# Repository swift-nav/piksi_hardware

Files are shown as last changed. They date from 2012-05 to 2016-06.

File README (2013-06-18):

Piksi Hardware
==============

Electronics design files for Swift Navigation projects - Eagle libraries,
schematics, and board files.

Copyright
=========

All files copyright (C) 2011-2013 Swift Navigation Inc.

License
=======

All files in this repository are licensed under the Creative Commons
Attribution Share-Alike 3.0 license - text available in LICENSE.

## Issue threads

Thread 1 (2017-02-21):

Piksi Multi Carrier Board,  RS232 Port SMD component problem

RaiBearG, 2017-02-21:
I was out on the field trying to test the multi and realized that the RS232 cable wouldn't connect with one of the carrier boards. Though the Multi was working and had an RTK fix, and the TX light on the board was blinking continuously. I was able to open the console and everything. Soon realized that if I pinched the board just the right spot, the communication would happen. Turns out, one of the SMD components (most likely a resistor) popped off from the bottom. It was working fine last night, so it must have been my  handling at the field today that caused it.

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

I am using the TTL uart port for now. Seems like that component was connected to the TI multiplexer. I am assuming, without it the signal always goes to the picoblade ttl connector.
Imma build a case to help prevent this from happening. Hopefully there will be ways to make this more robust. Field testing is usually very rough and hardcore.

Rai

silverjam, 2023-07-19:
Gonna close this issue @RaiBearG ;-)

Closed 2023-07-19.

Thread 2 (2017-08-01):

Piksi Multi Wishlist Changes

soulcmdc, 2017-08-01:
- [ ] Modify /RESETIN pullup to 1k and add a 1uF capacitor in parallel to fix issue: swift-nav/piksi_v3_bug_tracking#564

soulcmdc, 2017-08-01:
Wrong repo to toss this in

Closed 2017-08-01.

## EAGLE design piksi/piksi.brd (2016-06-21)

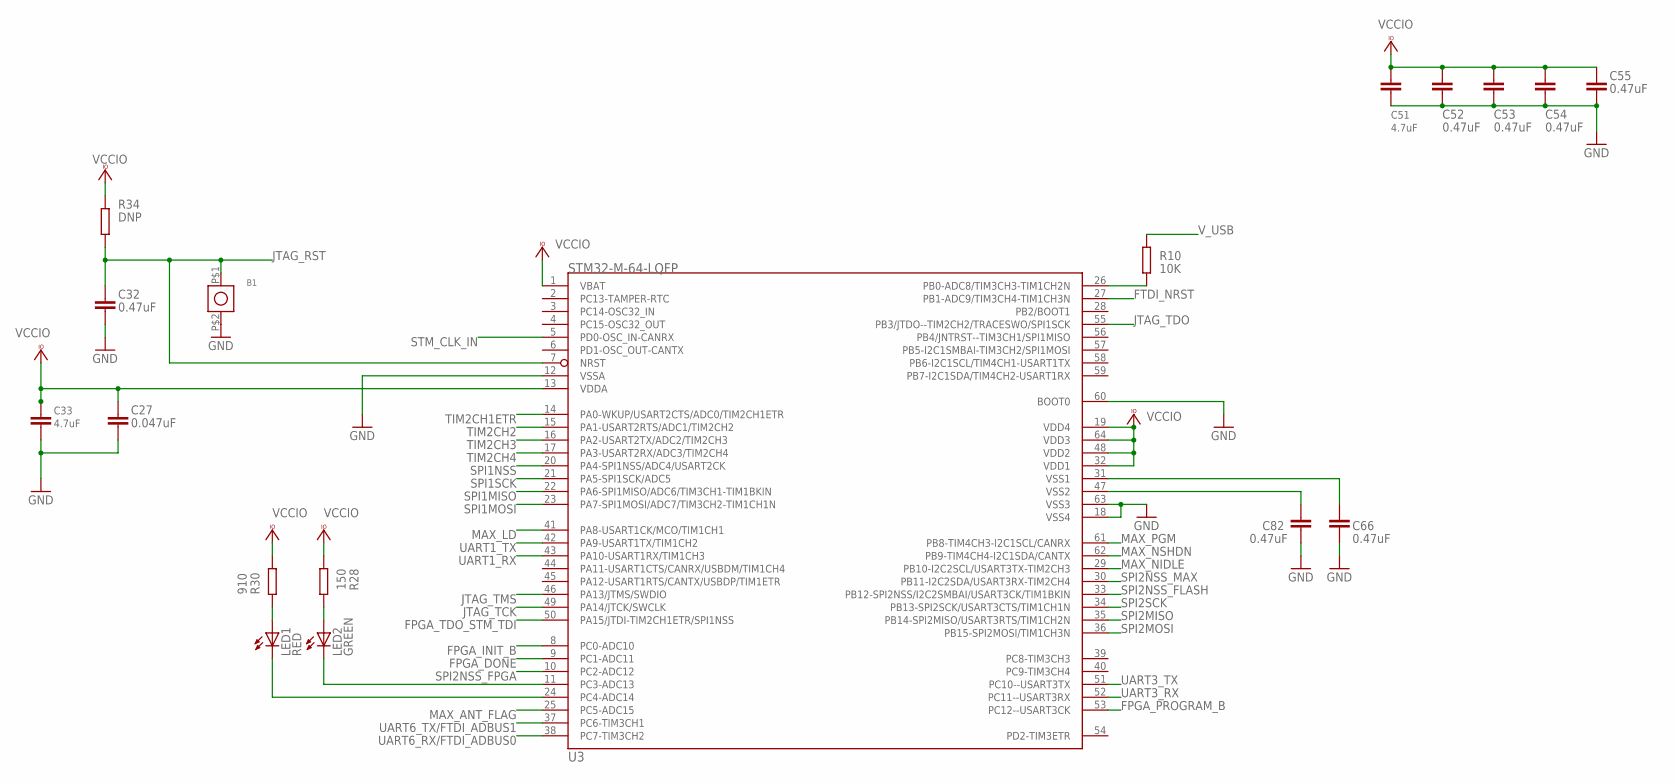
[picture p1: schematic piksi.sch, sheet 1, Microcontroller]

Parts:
B1: B3U-1000P
C27: 0.047uF; 0402-CAP
C32, C52, C53, C54, C55, C66, C82: 0.47uF; 0402-CAP
C33, C51: 4.7uF; 0603-CAP
LED1: RED; 0603-LED
LED2: GREEN; 0603-LED
R10: 10K; 0402-RES
R28: 150; 0402-RES
R30: 910; 0402-RES
R34: DNP; 0402-RES
U3: STM32-M-64-LQFP; LQFP64

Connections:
FPGA_DONE: U3.9 (PC1-ADC11); also elsewhere on the board
FPGA_INIT_B: U3.8 (PC0-ADC10); also elsewhere on the board
FPGA_PROGRAM_B: U3.53 (PC12--USART3CK); also elsewhere on the board
FPGA_TDO_STM_TDI: U3.50 (PA15/JTDI-TIM2CH1ETR/SPI1NSS); also elsewhere on the board
FTDI_NRST: U3.27 (PB1-ADC9/TIM3CH4-TIM1CH3N); also elsewhere on the board
GND: B1.P$2 (2), C27.P$2 (2), C32.P$2 (2), C33.P$1 (1), C51.P$1 (1), C52.P$2 (2), C53.P$2 (2), C54.P$2 (2), C55.P$2 (2), C66.P$2 (2), C82.P$1 (1), U3.12 (VSSA), U3.18 (VSS4), U3.60 (BOOT0), U3.63 (VSS3); also elsewhere on the board
JTAG_RST: B1.P$1 (1), C32.P$1 (1), R34.P$1 (1), U3.7 (NRST); also elsewhere on the board
JTAG_TCK: U3.49 (PA14/JTCK/SWCLK); also elsewhere on the board
JTAG_TDO: U3.55 (PB3/JTDO--TIM2CH2/TRACESWO/SPI1SCK); also elsewhere on the board
JTAG_TMS: U3.46 (PA13/JTMS/SWDIO); also elsewhere on the board
MAX_ANT_FLAG: U3.25 (PC5-ADC15); also elsewhere on the board
MAX_LD: U3.41 (PA8-USART1CK/MCO/TIM1CH1); also elsewhere on the board
MAX_NIDLE: U3.29 (PB10-I2C2SCL/USART3TX-TIM2CH3); also elsewhere on the board
MAX_NSHDN: U3.62 (PB9-TIM4CH4-I2C1SDA/CANTX); also elsewhere on the board
MAX_PGM: U3.61 (PB8-TIM4CH3-I2C1SCL/CANRX); also elsewhere on the board
unnamed: R10.P$1 (1), U3.26 (PB0-ADC8/TIM3CH3-TIM1CH2N)
unnamed: LED1.A, R30.P$1 (1)
unnamed: LED1.C, U3.24 (PC4-ADC14)
unnamed: LED2.A, R28.P$2 (2)
unnamed: LED2.C, U3.11 (PC3-ADC13)
SPI1MISO: U3.22 (PA6-SPI1MISO/ADC6/TIM3CH1-TIM1BKIN); also elsewhere on the board
SPI1MOSI: U3.23 (PA7-SPI1MOSI/ADC7/TIM3CH2-TIM1CH1N); also elsewhere on the board
SPI1NSS: U3.20 (PA4-SPI1NSS/ADC4/USART2CK); also elsewhere on the board
SPI1SCK: U3.21 (PA5-SPI1SCK/ADC5); also elsewhere on the board
SPI2MISO: U3.35 (PB14-SPI2MISO/USART3RTS/TIM1CH2N); also elsewhere on the board
SPI2MOSI: U3.36 (PB15-SPI2MOSI/TIM1CH3N); also elsewhere on the board
SPI2NSS_FLASH: U3.33 (PB12-SPI2NSS/I2C2SMBAI/USART3CK/TIM1BKIN); also elsewhere on the board
SPI2NSS_FPGA: U3.10 (PC2-ADC12)
SPI2NSS_MAX: U3.30 (PB11-I2C2SDA/USART3RX-TIM2CH4); also elsewhere on the board
SPI2SCK: U3.34 (PB13-SPI2SCK/USART3CTS/TIM1CH1N); also elsewhere on the board
STM_CLK_IN: U3.5 (PD0-OSC_IN-CANRX); also elsewhere on the board
TIM2CH1ETR: U3.14 (PA0-WKUP/USART2CTS/ADC0/TIM2CH1ETR); also elsewhere on the board
TIM2CH2: U3.15 (PA1-USART2RTS/ADC1/TIM2CH2); also elsewhere on the board
TIM2CH3: U3.16 (PA2-USART2TX/ADC2/TIM2CH3); also elsewhere on the board
TIM2CH4: U3.17 (PA3-USART2RX/ADC3/TIM2CH4); also elsewhere on the board
UART1_RX: U3.43 (PA10-USART1RX/TIM1CH3); also elsewhere on the board
UART1_TX: U3.42 (PA9-USART1TX/TIM1CH2); also elsewhere on the board
UART3_RX: U3.52 (PC11--USART3RX); also elsewhere on the board
UART3_TX: U3.51 (PC10--USART3TX); also elsewhere on the board
UART6_RX/FTDI_ADBUS0: U3.38 (PC7-TIM3CH2); also elsewhere on the board
UART6_TX/FTDI_ADBUS1: U3.37 (PC6-TIM3CH1); also elsewhere on the board
VCCIO: C27.P$1 (1), C33.P$2 (2), C51.P$2 (2), C52.P$1 (1), C53.P$1 (1), C54.P$1 (1), C55.P$1 (1), R28.P$1 (1), R30.P$2 (2), R34.P$2 (2), U3.1 (VBAT), U3.13 (VDDA), U3.19 (VDD4), U3.32 (VDD1), U3.48 (VDD2), U3.64 (VDD3); also elsewhere on the board
VSS1: C66.P$1 (1), U3.31 (VSS1)
VSS2: C82.P$2 (2), U3.47 (VSS2)
V_USB: R10.P$2 (2); also elsewhere on the board

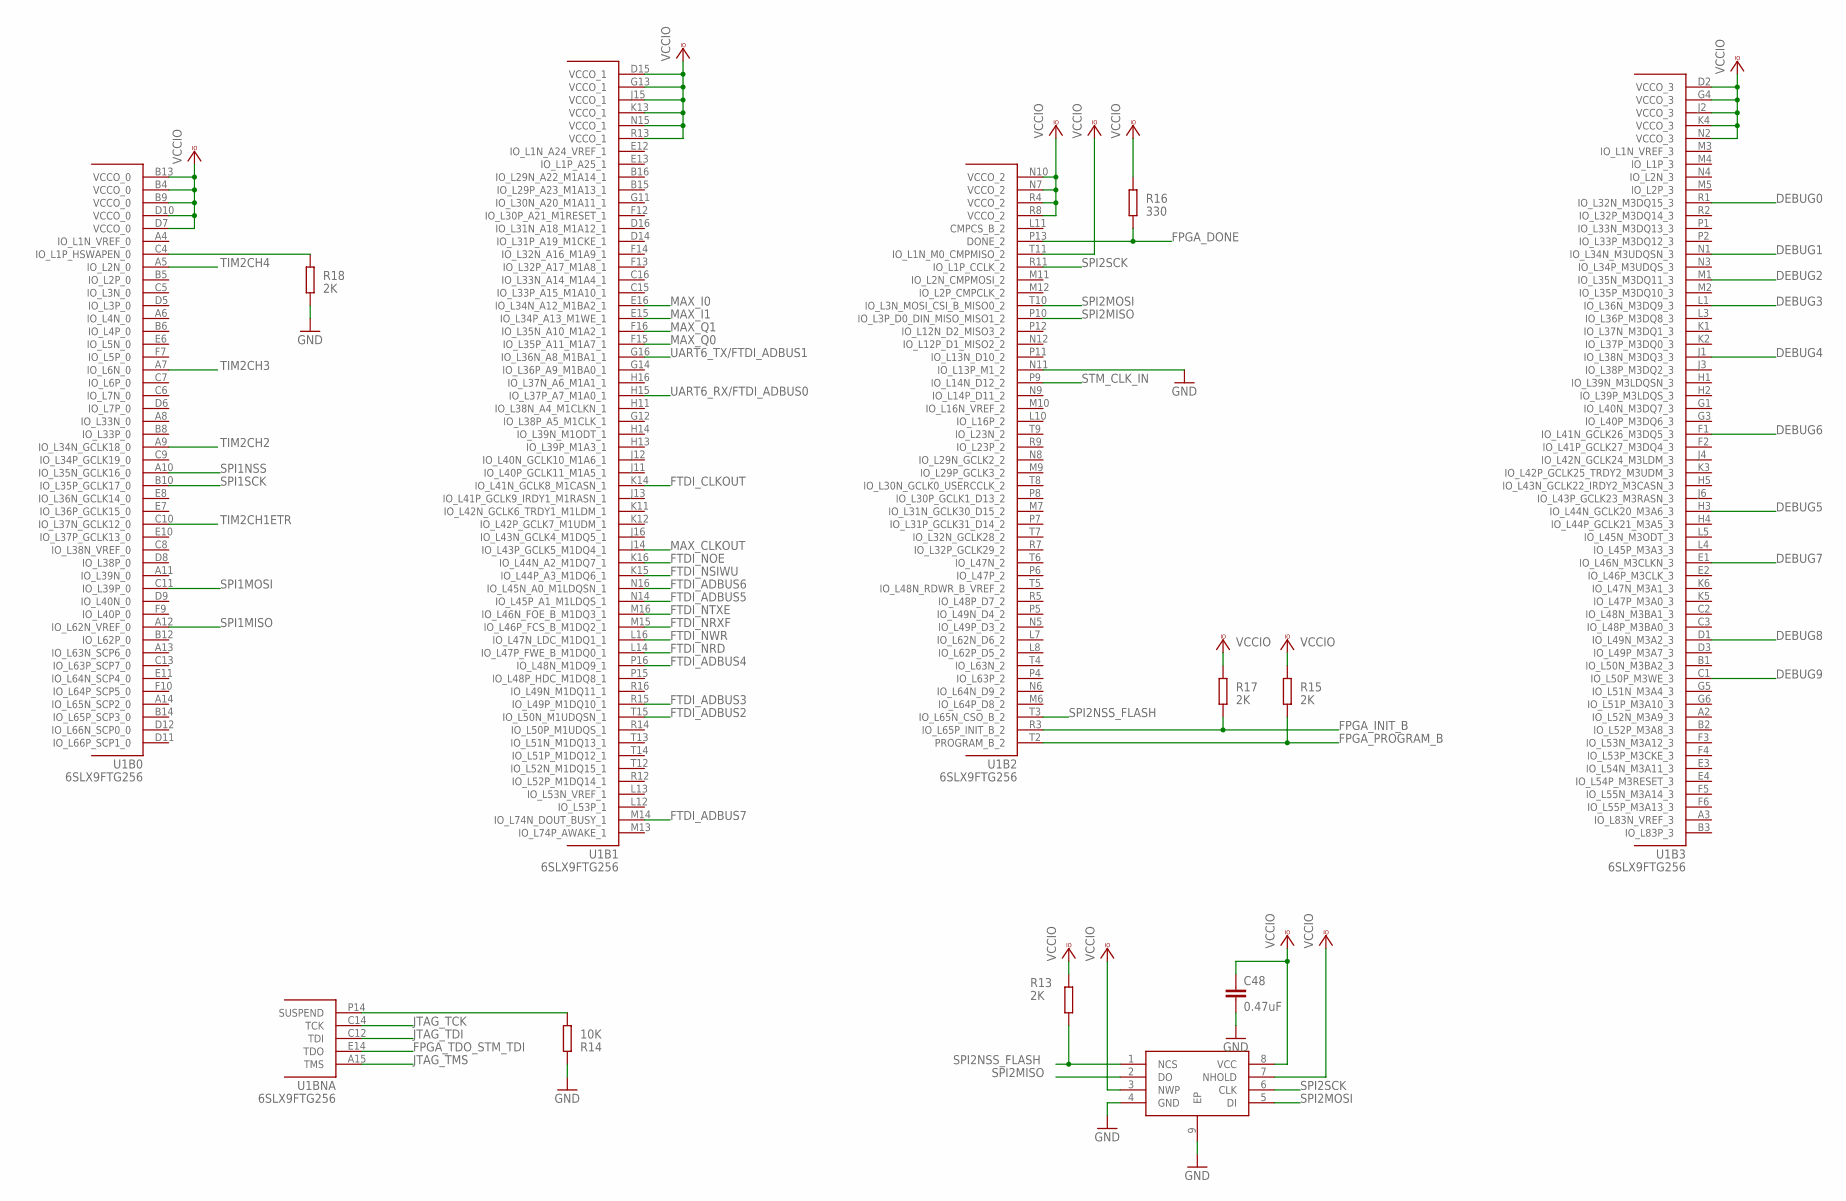
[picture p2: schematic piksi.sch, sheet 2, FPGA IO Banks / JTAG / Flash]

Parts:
C48: 0.47uF; 0402-CAP
R13, R15, R17, R18: 2K; 0402-RES
R14: 10K; 0402-RES
R16: 330; 0402-RES
U1: 6SLX9FTG256; FT256
U13: M25PX80; M25P80_MLP8

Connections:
DEBUG0: U1.R1 (IO_L32N_M3DQ15_3); also elsewhere on the board
DEBUG1: U1.N1 (IO_L34N_M3UDQSN_3); also elsewhere on the board
DEBUG2: U1.M1 (IO_L35N_M3DQ11_3); also elsewhere on the board
DEBUG3: U1.L1 (IO_L36N_M3DQ9_3); also elsewhere on the board
DEBUG4: U1.J1 (IO_L38N_M3DQ3_3); also elsewhere on the board
DEBUG5: U1.H3 (IO_L44N_GCLK20_M3A6_3); also elsewhere on the board
DEBUG6: U1.F1 (IO_L41N_GCLK26_M3DQ5_3); also elsewhere on the board
DEBUG7: U1.E1 (IO_L46N_M3CLKN_3); also elsewhere on the board
DEBUG8: U1.D1 (IO_L49N_M3A2_3); also elsewhere on the board
DEBUG9: U1.C1 (IO_L50P_M3WE_3); also elsewhere on the board
FPGA_DONE: R16.P$1 (1), U1.P13 (DONE_2); also elsewhere on the board
FPGA_INIT_B: R17.P$2 (2), U1.R3 (IO_L65P_INIT_B_2); also elsewhere on the board
FPGA_PROGRAM_B: R15.P$2 (2), U1.T2 (PROGRAM_B_2); also elsewhere on the board
FPGA_TDO_STM_TDI: U1.E14 (TDO); also elsewhere on the board
FTDI_ADBUS2: U1.T15 (IO_L50N_M1UDQSN_1); also elsewhere on the board
FTDI_ADBUS3: U1.R15 (IO_L49P_M1DQ10_1); also elsewhere on the board
FTDI_ADBUS4: U1.P16 (IO_L48N_M1DQ9_1); also elsewhere on the board
FTDI_ADBUS5: U1.N14 (IO_L45P_A1_M1LDQS_1); also elsewhere on the board
FTDI_ADBUS6: U1.N16 (IO_L45N_A0_M1LDQSN_1); also elsewhere on the board
FTDI_ADBUS7: U1.M14 (IO_L74N_DOUT_BUSY_1); also elsewhere on the board
FTDI_CLKOUT: U1.K14 (IO_L41N_GCLK8_M1CASN_1); also elsewhere on the board
FTDI_NOE: U1.K16 (IO_L44N_A2_M1DQ7_1); also elsewhere on the board
FTDI_NRD: U1.L14 (IO_L47P_FWE_B_M1DQ0_1); also elsewhere on the board
FTDI_NRXF: U1.M15 (IO_L46P_FCS_B_M1DQ2_1); also elsewhere on the board
FTDI_NSIWU: U1.K15 (IO_L44P_A3_M1DQ6_1); also elsewhere on the board
FTDI_NTXE: U1.M16 (IO_L46N_FOE_B_M1DQ3_1); also elsewhere on the board
FTDI_NWR: U1.L16 (IO_L47N_LDC_M1DQ1_1); also elsewhere on the board
GND: C48.P$2 (2), R14.P$2 (2), R18.P$1 (1), U1.N11 (IO_L13P_M1_2), U13.4 (GND), U13.9 (EP); also elsewhere on the board
JTAG_TCK: U1.C14 (TCK); also elsewhere on the board
JTAG_TDI: U1.C12 (TDI); also elsewhere on the board
JTAG_TMS: U1.A15 (TMS); also elsewhere on the board
MAX_CLKOUT: U1.J14 (IO_L43P_GCLK5_M1DQ4_1); also elsewhere on the board
MAX_I0: U1.E16 (IO_L34N_A12_M1BA2_1); also elsewhere on the board
MAX_I1: U1.E15 (IO_L34P_A13_M1WE_1); also elsewhere on the board
MAX_Q0: U1.F15 (IO_L35P_A11_M1A7_1); also elsewhere on the board
MAX_Q1: U1.F16 (IO_L35N_A10_M1A2_1); also elsewhere on the board
unnamed: R18.P$2 (2), U1.C4 (IO_L1P_HSWAPEN_0)
unnamed: R14.P$1 (1), U1.P14 (SUSPEND)
SPI1MISO: U1.A12 (IO_L62N_VREF_0); also elsewhere on the board
SPI1MOSI: U1.C11 (IO_L39P_0); also elsewhere on the board
SPI1NSS: U1.A10 (IO_L35N_GCLK16_0); also elsewhere on the board
SPI1SCK: U1.B10 (IO_L35P_GCLK17_0); also elsewhere on the board
SPI2MISO: U1.P10 (IO_L3P_D0_DIN_MISO_MISO1_2), U13.2 (DO); also elsewhere on the board
SPI2MOSI: U1.T10 (IO_L3N_MOSI_CSI_B_MISO0_2), U13.5 (DI); also elsewhere on the board
SPI2NSS_FLASH: R13.P$1 (1), U1.T3 (IO_L65N_CSO_B_2), U13.1 (NCS); also elsewhere on the board
SPI2SCK: U1.R11 (IO_L1P_CCLK_2), U13.6 (CLK); also elsewhere on the board
STM_CLK_IN: U1.P9 (IO_L14N_D12_2); also elsewhere on the board
TIM2CH1ETR: U1.C10 (IO_L37N_GCLK12_0); also elsewhere on the board
TIM2CH2: U1.A9 (IO_L34N_GCLK18_0); also elsewhere on the board
TIM2CH3: U1.A7 (IO_L6N_0); also elsewhere on the board
TIM2CH4: U1.A5 (IO_L2N_0); also elsewhere on the board
UART6_RX/FTDI_ADBUS0: U1.H15 (IO_L37P_A7_M1A0_1); also elsewhere on the board
UART6_TX/FTDI_ADBUS1: U1.G16 (IO_L36N_A8_M1BA1_1); also elsewhere on the board
VCCIO: C48.P$1 (1), R13.P$2 (2), R15.P$1 (1), R16.P$2 (2), R17.P$1 (1), U1.B4 (VCCO_0), U1.B9 (VCCO_0), U1.B13 (VCCO_0), U1.D2 (VCCO_3), U1.D7 (VCCO_0), U1.D10 (VCCO_0), U1.D15 (VCCO_1), U1.G4 (VCCO_3), U1.G13 (VCCO_1), U1.J2 (VCCO_3), U1.J15 (VCCO_1), U1.K4 (VCCO_3), U1.K13 (VCCO_1), U1.N2 (VCCO_3), U1.N7 (VCCO_2), U1.N10 (VCCO_2), U1.N15 (VCCO_1), U1.R4 (VCCO_2), U1.R8 (VCCO_2), U1.R13 (VCCO_1), U1.T11 (IO_L1N_M0_CMPMISO_2), U13.3 (NWP), U13.7 (NHOLD), U13.8 (VCC); also elsewhere on the board

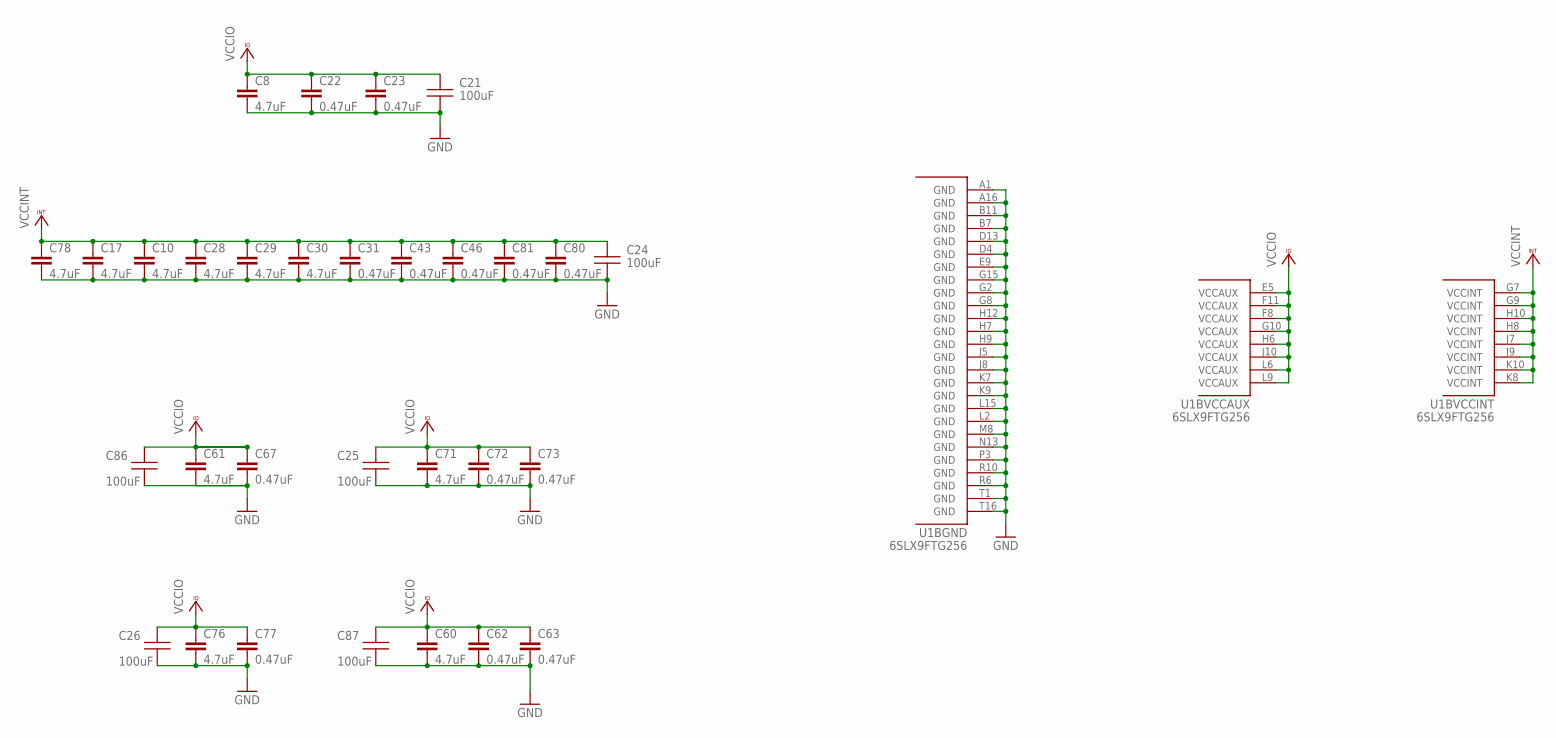
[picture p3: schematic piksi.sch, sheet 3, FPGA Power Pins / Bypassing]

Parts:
C8, C10, C17, C28, C29, C30, C60, C61, C71, C76, C78: 4.7uF; 0603-CAP
C21, C24, C25, C26, C86, C87: 100uF; C1210
C22, C23, C31, C43, C46, C62, C63, C67, C72, C73, C77, C80, C81: 0.47uF; 0402-CAP
U1: 6SLX9FTG256; FT256

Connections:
GND: C8.P$2 (2), C10.P$2 (2), C17.P$2 (2), C21.P$2 (2), C22.P$2 (2), C23.P$2 (2), C24.P$2 (2), C25.P$2 (2), C26.P$2 (2), C28.P$2 (2), C29.P$2 (2), C30.P$2 (2), C31.P$2 (2), C43.P$2 (2), C46.P$2 (2), C60.P$2 (2), C61.P$2 (2), C62.P$2 (2), C63.P$2 (2), C67.P$2 (2), C71.P$2 (2), C72.P$2 (2), C73.P$2 (2), C76.P$2 (2), C77.P$2 (2), C78.P$2 (2), C80.P$2 (2), C81.P$2 (2), C86.P$2 (2), C87.P$2 (2), U1.A1 (GND), U1.A16 (GND), U1.B7 (GND), U1.B11 (GND), U1.D4 (GND), U1.D13 (GND), U1.E9 (GND), U1.G2 (GND), U1.G8 (GND), U1.G15 (GND), U1.H7 (GND), U1.H9 (GND), U1.H12 (GND), U1.J5 (GND), U1.J8 (GND), U1.K7 (GND), U1.K9 (GND), U1.L2 (GND), U1.L15 (GND), U1.M8 (GND), U1.N13 (GND), U1.P3 (GND), U1.R6 (GND), U1.R10 (GND), U1.T1 (GND), U1.T16 (GND); also elsewhere on the board
VCCINT: C10.P$1 (1), C17.P$1 (1), C24.P$1 (1), C28.P$1 (1), C29.P$1 (1), C30.P$1 (1), C31.P$1 (1), C43.P$1 (1), C46.P$1 (1), C78.P$1 (1), C80.P$1 (1), C81.P$1 (1), U1.G7 (VCCINT), U1.G9 (VCCINT), U1.H8 (VCCINT), U1.H10 (VCCINT), U1.J7 (VCCINT), U1.J9 (VCCINT), U1.K8 (VCCINT), U1.K10 (VCCINT); also elsewhere on the board
VCCIO: C8.P$1 (1), C21.P$1 (1), C22.P$1 (1), C23.P$1 (1), C25.P$1 (1), C26.P$1 (1), C60.P$1 (1), C61.P$1 (1), C62.P$1 (1), C63.P$1 (1), C67.P$1 (1), C71.P$1 (1), C72.P$1 (1), C73.P$1 (1), C76.P$1 (1), C77.P$1 (1), C86.P$1 (1), C87.P$1 (1), U1.E5 (VCCAUX), U1.F8 (VCCAUX), U1.F11 (VCCAUX), U1.G10 (VCCAUX), U1.H6 (VCCAUX), U1.J10 (VCCAUX), U1.L6 (VCCAUX), U1.L9 (VCCAUX); also elsewhere on the board

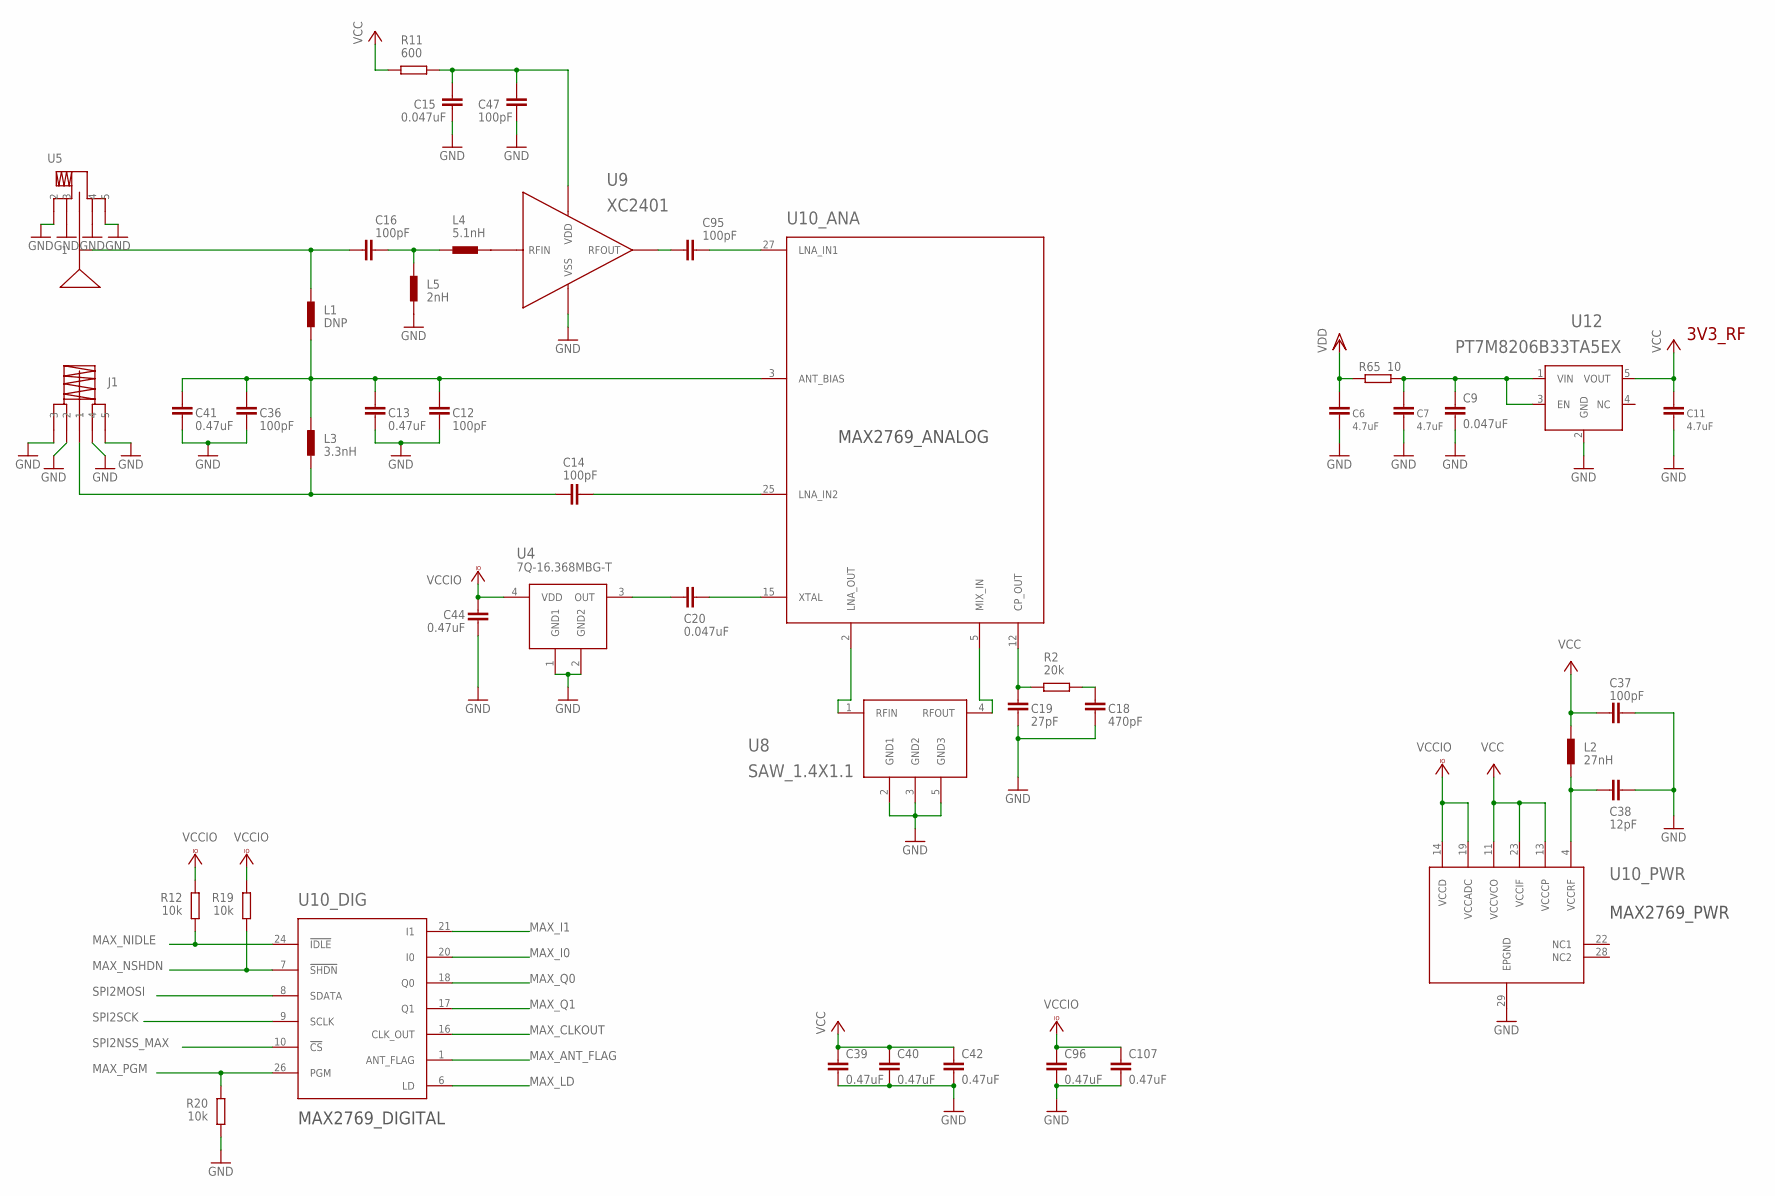
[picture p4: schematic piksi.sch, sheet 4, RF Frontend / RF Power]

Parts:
C6, C7, C11: 4.7uF; 0603-CAP
C9, C15, C20: 0.047uF; 0402-CAP
C12, C14, C16, C36, C37, C47, C95: 100pF; 0402-CAP
C13, C39, C40, C41, C42, C44, C96, C107: 0.47uF; 0402-CAP
C18: 470pF; 0402-CAP
C19: 27pF; 0402-CAP
C38: 12pF; 0402-CAP
J1: SMA_EDGE
L1: DNP; 0402-IND
L2: 27nH; 0402-IND
L3: 3.3nH; 0402-IND
L4: 5.1nH; 0402-IND
L5: 2nH; 0402-IND
R2: 20k; 0402-RES
R11: 600; 0402-RES
R12, R19, R20: 10k; 0402-RES
R65: 10; 0402-RES
U4: 7Q-16.368MBG-T; TCX_7Q
U5: SMA_PATCH_SMDGND
U8: SAW_1.4X1.1
U9: XC2401
U10: MAX2769
U12: PT7M8206B33TA5EX

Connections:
FE_CLK: C20.P$2 (2), U4.3 (OUT)
GND: C6.P$1 (1), C7.P$1 (1), C9.P$2 (2), C11.P$1 (1), C12.P$1 (1), C13.P$1 (1), C15.P$1 (1), C18.P$2 (2), C19.P$2 (2), C36.P$1 (1), C37.P$2 (2), C38.P$2 (2), C39.P$2 (2), C40.P$2 (2), C41.P$1 (1), C42.P$2 (2), C44.P$2 (2), C47.P$1 (1), C96.P$2 (2), C107.P$2 (2), J1.P2 (2), J1.P3 (3), J1.P4 (4), J1.P5 (5), L5.P$1 (1), R20.P$1 (1), U4.1 (GND1), U4.2 (GND2), U5.2, U5.3, U5.4, U5.5, U8.2 (GND1), U8.3 (GND2), U8.5 (GND3), U9.3 (VSS), U10.29 (EPGND), U12.2 (GND); also elsewhere on the board
MAX_ANT_FLAG: U10.1 (ANT_FLAG); also elsewhere on the board
MAX_CLKOUT: U10.16 (CLK_OUT); also elsewhere on the board
MAX_I0: U10.20 (I0); also elsewhere on the board
MAX_I1: U10.21 (I1); also elsewhere on the board
MAX_LD: U10.6 (LD); also elsewhere on the board
MAX_NIDLE: R12.P$1 (1), U10.24 (!IDLE); also elsewhere on the board
MAX_NSHDN: R19.P$1 (1), U10.7 (!SHDN); also elsewhere on the board
MAX_PGM: R20.P$2 (2), U10.26 (PGM); also elsewhere on the board
MAX_Q0: U10.18 (Q0); also elsewhere on the board
MAX_Q1: U10.17 (Q1); also elsewhere on the board
unnamed: L4.P$2 (2), U9.4 (RFIN)
unnamed: C18.P$1 (1), R2.P$1 (1)
unnamed: C19.P$1 (1), R2.P$2 (2), U10.12 (CP_OUT)
unnamed: U8.1 (RFIN), U10.2 (LNA_OUT)
unnamed: C20.P$1 (1), U10.15 (XTAL)
unnamed: U8.4 (RFOUT), U10.5 (MIX_IN)
unnamed: C14.P$1 (1), J1.P1 (1), L3.P$1 (1)
unnamed: C12.P$2 (2), C13.P$2 (2), C36.P$2 (2), C41.P$2 (2), L1.P$1 (1), L3.P$2 (2), U10.3 (ANT_BIAS)
unnamed: C95.P$2 (2), U10.27 (LNA_IN1)
unnamed: C16.P$1 (1), L1.P$2 (2), U5.1
unnamed: C38.P$1 (1), L2.P$1 (1), U10.4 (VCCRF)
unnamed: C14.P$2 (2), U10.25 (LNA_IN2)
unnamed: C16.P$2 (2), L4.P$1 (1), L5.P$2 (2)
unnamed: C95.P$1 (1), U9.2 (RFOUT)
unnamed: C15.P$2 (2), C47.P$2 (2), R11.P$1 (1), U9.1 (VDD)
unnamed: C7.P$2 (2), C9.P$1 (1), R65.P$2 (2), U12.1 (VIN), U12.3 (EN)
SPI2MOSI: U10.8 (SDATA); also elsewhere on the board
SPI2NSS_MAX: U10.10 (!CS); also elsewhere on the board
SPI2SCK: U10.9 (SCLK); also elsewhere on the board
VCC: C11.P$2 (2), C37.P$1 (1), C39.P$1 (1), C40.P$1 (1), C42.P$1 (1), L2.P$2 (2), R11.P$2 (2), U10.11 (VCCVCO), U10.13 (VCCCP), U10.23 (VCCIF), U12.5 (VOUT)
VCCIO: C44.P$1 (1), C96.P$1 (1), C107.P$1 (1), R12.P$2 (2), R19.P$2 (2), U4.4 (VDD), U10.14 (VCCD), U10.19 (VCCADC); also elsewhere on the board
VDD: C6.P$2 (2), R65.P$1 (1); also elsewhere on the board

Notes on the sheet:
3V3_RF

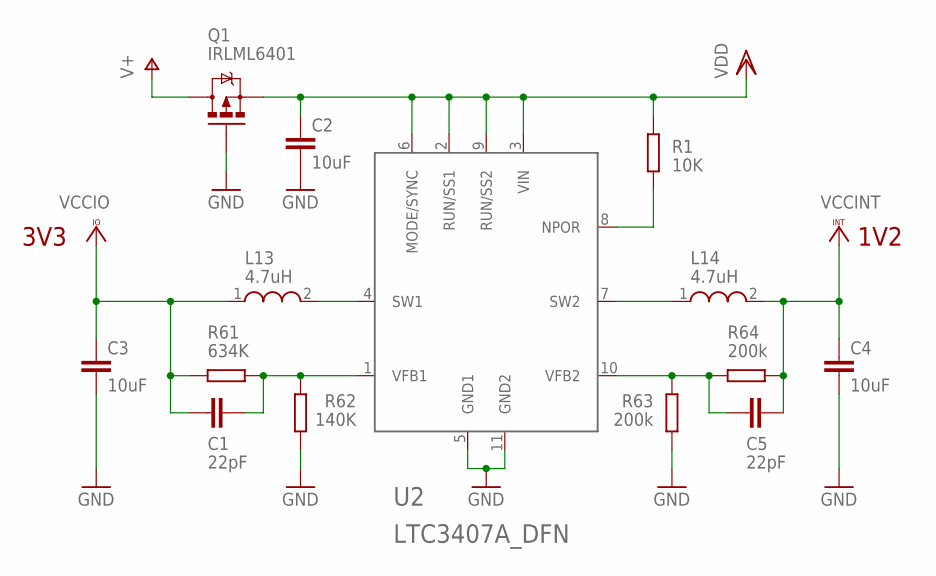
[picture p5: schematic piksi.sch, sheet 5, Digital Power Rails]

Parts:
C1, C5: 22pF; 0402-CAP
C2, C3, C4: 10uF; 1206-CAP
L13, L14: 4.7uH; LQM2HPN4R7MG0L
Q1: IRLML6401; SOT23-3
R1: 10K; 0402-RES
R61: 634K; 0402-RES
R62: 140K; 0402-RES
R63, R64: 200k; 0402-RES
U2: LTC3407A_DFN; DFN10

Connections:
GND: C2.P$2 (2), C3.P$2 (2), C4.P$2 (2), Q1.1 (G), R62.P$2 (2), R63.P$2 (2), U2.5 (GND1), U2.11 (GND2); also elsewhere on the board
unnamed: R1.P$1 (1), U2.8 (NPOR)
unnamed: L13.2, U2.4 (SW1)
unnamed: L14.1, U2.7 (SW2)
unnamed: C1.P$1 (1), R61.P$1 (1), R62.P$1 (1), U2.1 (VFB1)
unnamed: C5.P$2 (2), R63.P$1 (1), R64.P$1 (1), U2.10 (VFB2)
V+: Q1.3 (D); also elsewhere on the board
VCCINT: C4.P$1 (1), C5.P$1 (1), L14.2, R64.P$2 (2); also elsewhere on the board
VCCIO: C1.P$2 (2), C3.P$1 (1), L13.1, R61.P$2 (2); also elsewhere on the board
VDD: C2.P$1 (1), Q1.2 (S), R1.P$2 (2), U2.2 (RUN/SS1), U2.3 (VIN), U2.6 (MODE/SYNC), U2.9 (RUN/SS2); also elsewhere on the board

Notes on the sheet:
1V2
3V3

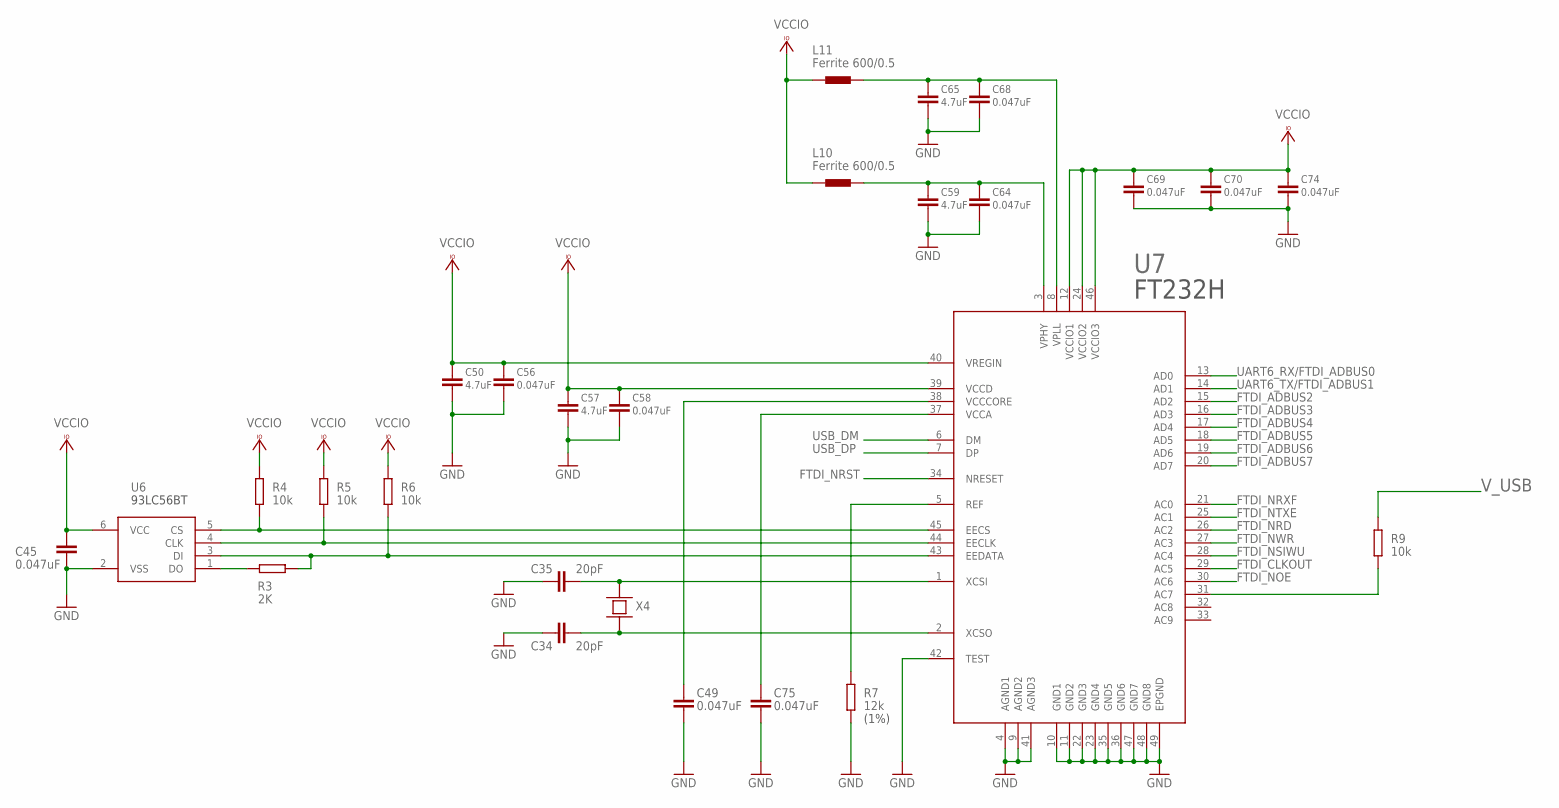
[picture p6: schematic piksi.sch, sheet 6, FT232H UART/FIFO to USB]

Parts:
C34, C35: 20pF; 0402-CAP
C45: 0.047uF; C0402
C49, C56, C58, C64, C68, C70, C74, C75: 0.047uF; 0402-CAP
C50, C57, C59, C65: 4.7uF; 0603-CAP
C69: 0.047uF; C0603K
L10, L11: Ferrite 600/0.5; 0805-IND
R3: 2K; 0402-RES
R4, R5, R6, R9: 10k; 0402-RES
R7: 12k; 0402-RES
U6: 93LC56BT-I/OT; 93AA56BT-I/OT
U7: FT232HQ
X4: NX5032GA-12M; NX5032GA

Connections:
FTDI_ADBUS2: U7.15 (AD2); also elsewhere on the board
FTDI_ADBUS3: U7.16 (AD3); also elsewhere on the board
FTDI_ADBUS4: U7.17 (AD4); also elsewhere on the board
FTDI_ADBUS5: U7.18 (AD5); also elsewhere on the board
FTDI_ADBUS6: U7.19 (AD6); also elsewhere on the board
FTDI_ADBUS7: U7.20 (AD7); also elsewhere on the board
FTDI_CLKOUT: U7.29 (AC5); also elsewhere on the board
FTDI_NOE: U7.30 (AC6); also elsewhere on the board
FTDI_NRD: U7.26 (AC2); also elsewhere on the board
FTDI_NRST: U7.34 (NRESET); also elsewhere on the board
FTDI_NRXF: U7.21 (AC0); also elsewhere on the board
FTDI_NSIWU: U7.28 (AC4); also elsewhere on the board
FTDI_NTXE: U7.25 (AC1); also elsewhere on the board
FTDI_NWR: U7.27 (AC3); also elsewhere on the board
GND: C34.P$2 (2), C35.P$2 (2), C45.2, C49.P$2 (2), C50.P$1 (1), C56.P$2 (2), C57.P$1 (1), C58.P$2 (2), C59.P$1 (1), C64.P$2 (2), C65.P$1 (1), C68.P$2 (2), C69.2, C70.P$2 (2), C74.P$2 (2), C75.P$2 (2), R7.P$2 (2), U6.2 (VSS), U7.4 (AGND1), U7.9 (AGND2), U7.10 (GND1), U7.11 (GND2), U7.22 (GND3), U7.23 (GND4), U7.35 (GND5), U7.36 (GND6), U7.41 (AGND3), U7.42 (TEST), U7.47 (GND7), U7.48 (GND8), U7.49 (EPGND); also elsewhere on the board
unnamed: C34.P$1 (1), U7.2 (XCSO), X4.2
unnamed: C35.P$1 (1), U7.1 (XCSI), X4.1
unnamed: C49.P$1 (1), U7.38 (VCCCORE)
unnamed: R9.P$2 (2), U7.31 (AC7)
unnamed: C65.P$2 (2), C68.P$1 (1), L11.P$2 (2), U7.8 (VPLL)
unnamed: R4.P$2 (2), U6.5 (CS), U7.45 (EECS)
unnamed: R5.P$2 (2), U6.4 (CLK), U7.44 (EECLK)
unnamed: R3.P$1 (1), R6.P$2 (2), U6.3 (DI), U7.43 (EEDATA)
unnamed: R3.P$2 (2), U6.1 (DO)
unnamed: C59.P$2 (2), C64.P$1 (1), L10.P$2 (2), U7.3 (VPHY)
unnamed: C75.P$1 (1), U7.37 (VCCA)
unnamed: R7.P$1 (1), U7.5 (REF)
UART6_RX/FTDI_ADBUS0: U7.13 (AD0); also elsewhere on the board
UART6_TX/FTDI_ADBUS1: U7.14 (AD1); also elsewhere on the board
USB_DM: U7.6 (DM); also elsewhere on the board
USB_DP: U7.7 (DP); also elsewhere on the board
VCCIO: C45.1, C50.P$2 (2), C56.P$1 (1), C57.P$2 (2), C58.P$1 (1), C69.1, C70.P$1 (1), C74.P$1 (1), L10.P$1 (1), L11.P$1 (1), R4.P$1 (1), R5.P$1 (1), R6.P$1 (1), U6.6 (VCC), U7.12 (VCCIO1), U7.24 (VCCIO2), U7.39 (VCCD), U7.40 (VREGIN), U7.46 (VCCIO3); also elsewhere on the board
V_USB: R9.P$1 (1); also elsewhere on the board

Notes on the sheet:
(1%)

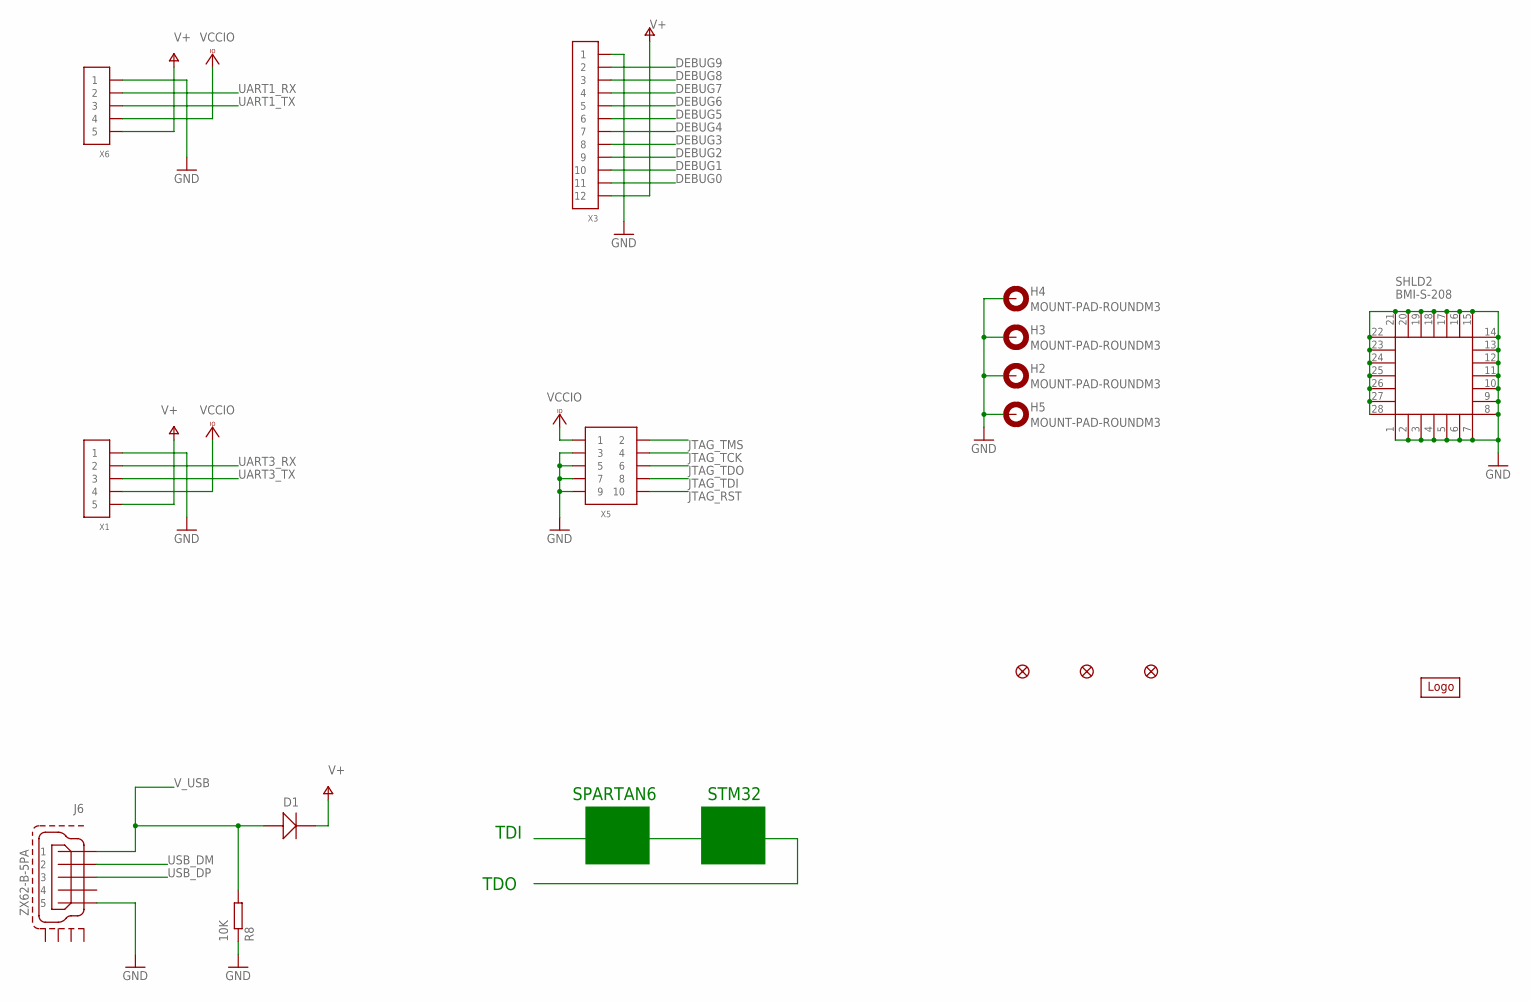
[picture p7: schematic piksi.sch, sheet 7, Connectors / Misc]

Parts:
D1: MBR0520; SOD-123
H2, H3, H4, H5: MOUNT-PAD-ROUNDM3; M3-PAD
J6: ZX62-B-5PA
JP8, JP9, JP10: FIDUCIAL1.5X3; FIDUCIAL-1.5X3
R8: 10K; 0402-RES
SHLD2: BMI-S-208
U$2: LOGOLOGO3_SMALL; LOGO3_SMALL
X1, X6: CONN_5-1-53261; PB-53261-05
X3: FPGA DEBUG; PB-53261-12
X5: CONN_5-2; FTSH-105-D

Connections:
DEBUG0: X3.11; also elsewhere on the board
DEBUG1: X3.10; also elsewhere on the board
DEBUG2: X3.9; also elsewhere on the board
DEBUG3: X3.8; also elsewhere on the board
DEBUG4: X3.7; also elsewhere on the board
DEBUG5: X3.6; also elsewhere on the board
DEBUG6: X3.5; also elsewhere on the board
DEBUG7: X3.4; also elsewhere on the board
DEBUG8: X3.3; also elsewhere on the board
DEBUG9: X3.2; also elsewhere on the board
GND: H2.B3,0, H3.B3,0, H4.B3,0, H5.B3,0, J6.PIN_5 (5), R8.P$1 (1), SHLD2.1, SHLD2.2, SHLD2.3, SHLD2.4, SHLD2.5, SHLD2.6, SHLD2.7, SHLD2.8, SHLD2.9, SHLD2.10, SHLD2.11, SHLD2.12, SHLD2.13, SHLD2.14, SHLD2.15, SHLD2.16, SHLD2.17, SHLD2.18, SHLD2.19, SHLD2.20, SHLD2.21, SHLD2.22, SHLD2.23, SHLD2.24, SHLD2.25, SHLD2.26, SHLD2.27, SHLD2.28, X1.1, X3.1, X5.3, X5.5, X5.7, X5.9, X6.1; also elsewhere on the board
JTAG_RST: X5.10; also elsewhere on the board
JTAG_TCK: X5.4; also elsewhere on the board
JTAG_TDI: X5.8; also elsewhere on the board
JTAG_TDO: X5.6; also elsewhere on the board
JTAG_TMS: X5.2; also elsewhere on the board
UART1_RX: X6.2; also elsewhere on the board
UART1_TX: X6.3; also elsewhere on the board
UART3_RX: X1.2; also elsewhere on the board
UART3_TX: X1.3; also elsewhere on the board
USB_DM: J6.PIN_2 (2); also elsewhere on the board
USB_DP: J6.PIN_3 (3); also elsewhere on the board
V+: D1.2, X1.5, X3.12, X6.5; also elsewhere on the board
VCCIO: X1.4, X5.1, X6.4; also elsewhere on the board
V_USB: D1.1, J6.PIN_1 (1), R8.P$2 (2); also elsewhere on the board

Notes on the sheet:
TDI
TDO
STM32
SPARTAN6

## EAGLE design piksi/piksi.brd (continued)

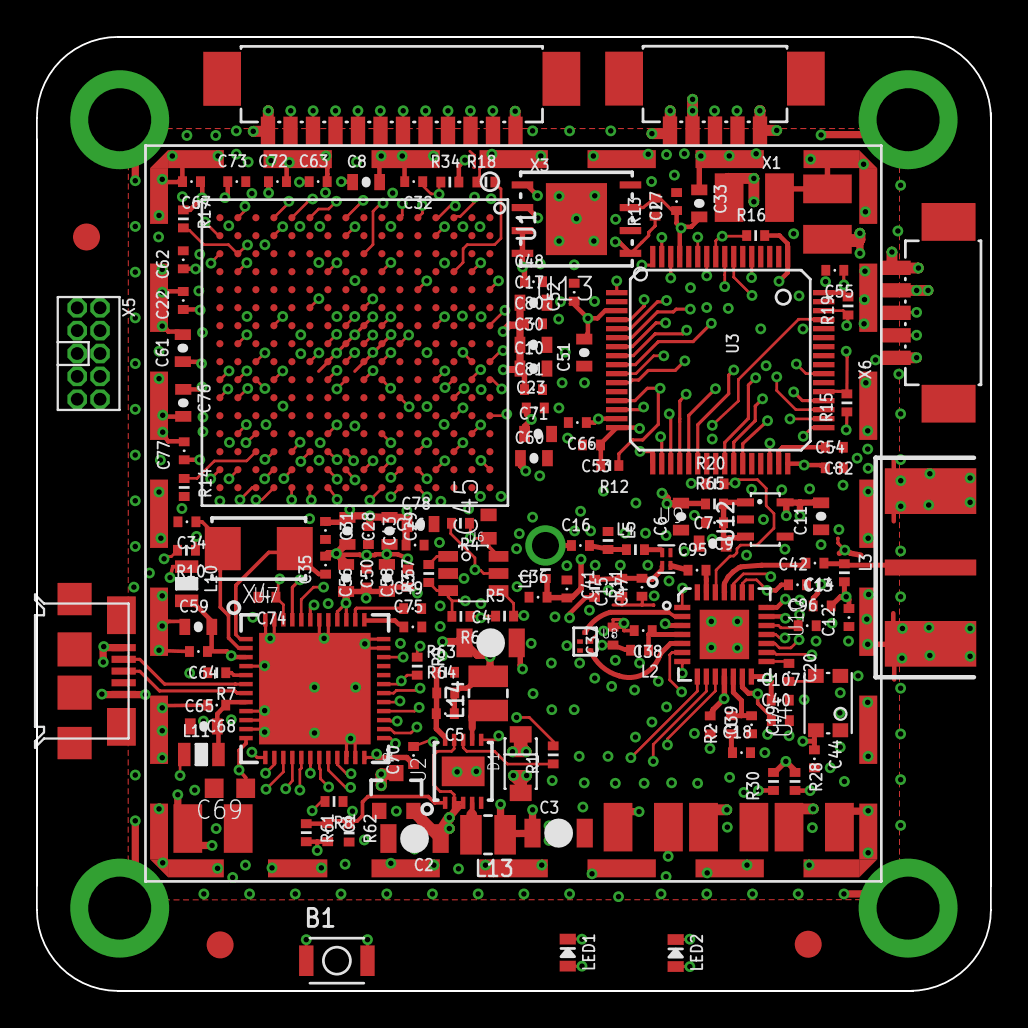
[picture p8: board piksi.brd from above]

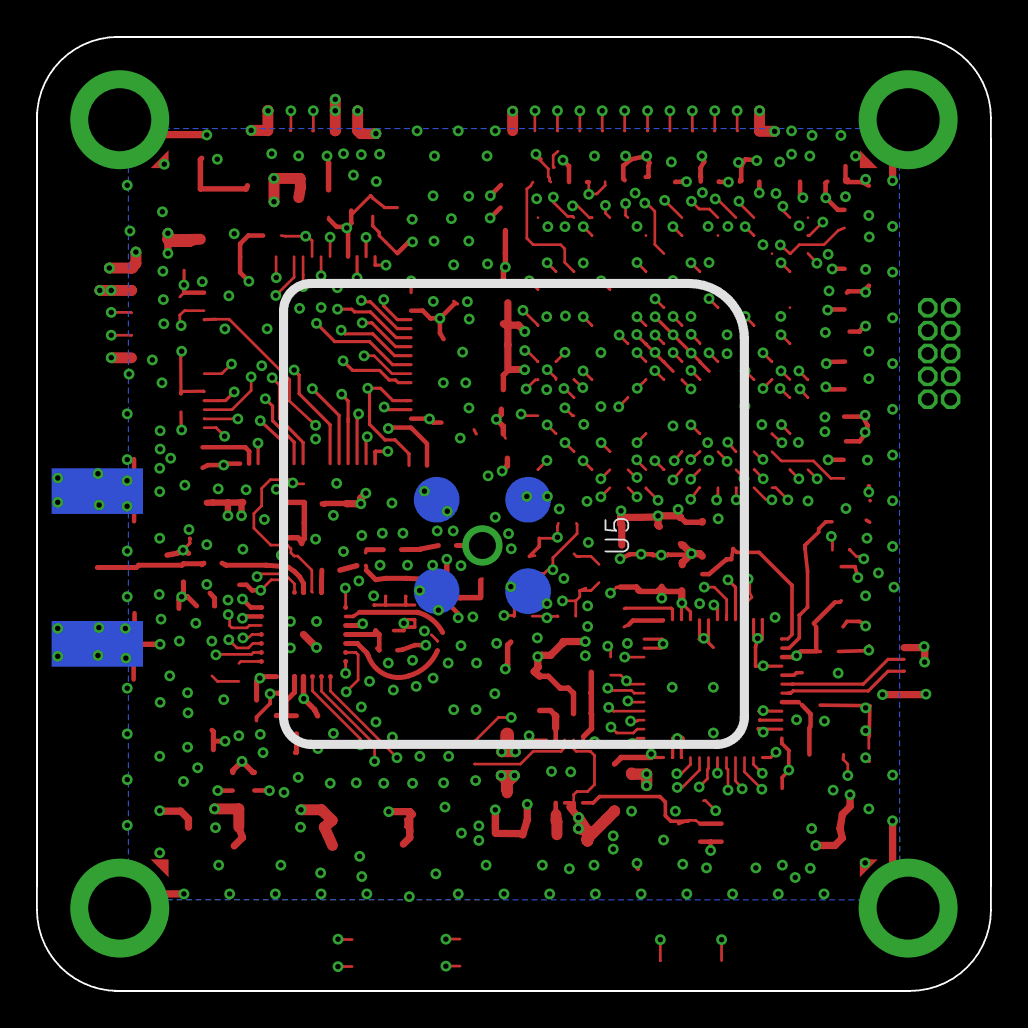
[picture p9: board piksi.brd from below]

Board: 6 copper layers, 53.0 x 53.0 mm, 157 parts (2 on the bottom side), 115 nets.

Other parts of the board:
U$1: LOGOINITIALS; INITIALS

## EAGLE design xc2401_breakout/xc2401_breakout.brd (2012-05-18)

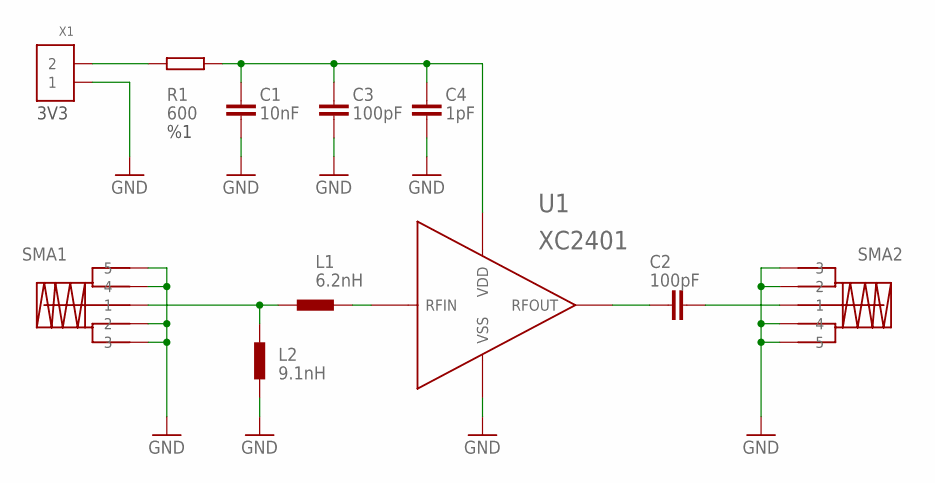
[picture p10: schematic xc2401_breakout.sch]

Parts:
C1: 10nF; 0402-CAP
C2, C3: 100pF; 0402-CAP
C4: 1pF; 0402-CAP
L1: 6.2nH; 0402-IND
L2: 9.1nH; 0402-IND
R1: 600; 0402-RES
SMA1, SMA2: SMA_EDGE
U1: XC2401
X1: CONN_2-1-53261; PB-53261-02

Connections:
GND: C1.P$2 (2), C3.P$2 (2), C4.P$2 (2), L2.P$1 (1), SMA1.P2 (2), SMA1.P3 (3), SMA1.P4 (4), SMA1.P5 (5), SMA2.P2 (2), SMA2.P3 (3), SMA2.P4 (4), SMA2.P5 (5), U1.3 (VSS), X1.1
unnamed: C1.P$1 (1), C3.P$1 (1), C4.P$1 (1), R1.P$2 (2), U1.1 (VDD)
unnamed: C2.P$1 (1), U1.2 (RFOUT)
unnamed: C2.P$2 (2), SMA2.P1 (1)
unnamed: L1.P$1 (1), L2.P$2 (2), SMA1.P1 (1)
unnamed: L1.P$2 (2), U1.4 (RFIN)
unnamed: R1.P$1 (1), X1.2

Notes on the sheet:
3V3

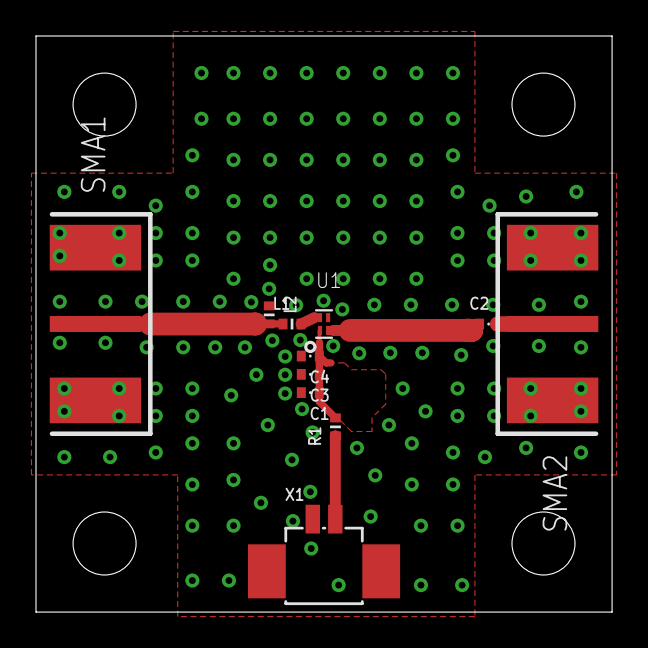
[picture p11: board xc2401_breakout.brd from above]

Board: 2 copper layers, 32.0 x 32.0 mm, 11 parts (0 on the bottom side), 7 nets.

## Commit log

2012-03-06 Initial import of JobyGNSS v2.1 design in Eagle 5 format.
    [jobygnss_v2.1_final.brd, jobygnss_v2.1_final.sch]
2012-03-06 Renamed and converted to Eagle 6 format.
    [jobygnss_v2.1_final.brd, jobygnss_v2.1_final.sch, swift-nav.brd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]
2012-03-10 Need to add different TCXO to schematic then ready for review
    [swift-nav.brd, swift-nav.sch]
2012-03-12 Changed TXCO to TXC 7Q-16.368MBG-T (3v3, 16.368MHz, 0.5/2 2PPM TCXO) And added library with 7Q-16.368MBG-T package in it
    [swift-nav.sch]
2012-03-12 Rearranged schematic a bit and cleared up some errors
    [swift-nav.sch]
2012-03-14 Some changes post schematic review, more to come... Removed FPGA_D1_MISO2 and FPGA_D2_MISO3, changed R12 and R11 to hard shorts to VCCIO Removed Molex connector Replaced all +5V power symbols with V+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
    [swift-nav.sch]
2012-03-14 Removed ferrite leading to VDDA pin on STM Changed UART headers to 5 pin with both 3v3 and V+ pins Changed STM32-LQFP64 symbol to F4 (VCAP_1 and VCAP_2 replace VSS1 and VSS2)
    [swift-nav.sch]
2012-03-14 Added button to JTAG_RST line Added libraries used in design of 2.1
    [swift-nav.sch]
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2012-03-16 Working on the layout
    [swift-nav.brd, swift-nav.sch]
2012-03-20 Workin on layout. Finished placing everything but a few resistors. Should we size down to a smaller can? Add FTDI 232H?
    [swift-nav.brd, swift-nav.sch]
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2012-03-21 Starting placing FT232H components
    [swift-nav.brd, swift-nav.sch]
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2012-03-23 All components placed, but clearances aren't going to be enough for assembly so have to move stuff to the bottom side.
    [swift-nav.brd, swift-nav.sch]
2012-03-23 All components placed inside can with 20 mil clearances for assembly
    [swift-nav.brd, swift-nav.sch]
2012-03-27 Just a bit of routing between the STM and FPGA left
    [swift-nav.brd, swift-nav.sch]
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2012-03-28 Schematic warnings checked, no problems
    [swift-nav.brd, swift-nav.sch]
2012-03-28 Fixing DRC errors on board
    [swift-nav.brd]
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2012-03-29 Corrected ground plane / traces under side mount SMA and straightened some traces
    [swift-nav.brd]
2012-03-30 Cleaned up routing somewhat, shortened trace lengths where easy to do so
    [swift-nav.brd]
2012-03-30 Changed positions of picoblade headers and JTAG header, re-routing Rotated Spartan6 180 degrees
    [swift-nav.brd, swift-nav.sch]
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2012-04-03 All signals routed except caps on bottom layer
    [swift-nav.brd, swift-nav.sch]
2012-04-03 Caps placed on bottom and board cleaned up a bit
    [swift-nav.brd, swift-nav.sch]
2012-04-03 Some clean-up and DRC done. Errors left un-approved in DRC are cases where via-to-pad spacing or pad-to-pad spacing (same signal) is less than 6 mil
    [swift-nav.brd, swift-nav.sch]
2012-04-03 Few more minor changes, cleaned up top silkscreen a bit
    [swift-nav.brd, swift-nav.sch]
2012-04-04 Cleaned up soldermask clearances
    [swift-nav.brd]
2012-04-04 Removed last airwire (not that it was a problem).
    [swift-nav.brd]
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2012-04-04 Bottom silk should be mirrored (duh). Added initial attempt at logo.
    [swift-nav.brd]
2012-04-04 Changed mounting holes to fit an M3 bolt and to be plated through.
    [swift-nav.brd, swift-nav.sch]
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2012-04-04 Fix small error in logo.
    [swift-nav.brd, swift-nav.sch]
2012-04-04 Moved around a few vias and added a few more.
    [swift-nav.brd]
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2012-04-04 Fix restrict layer on fiducials.
    [swift-nav.brd, swift-nav.sch]
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2012-04-05 Changed FT232 AC7 pullup to V_USB instead of VCCIO Changed RF input from V+ (before PMOS) to VDD (after PMOS) Added pulldown resistor to V_USB
    [swift-nav.brd, swift-nav.sch]
2012-04-05 Removed extra mounting hole. Still need to move mounting holes in
    [swift-nav.brd, swift-nav.sch]
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2012-04-05 Cut off corners of BMIS-208 shield to accomodate mounting holes. Need to shrink mounting hole pads
    [swift-nav.brd, swift-nav.sch]
2012-04-05 Changed mounting hole copper width to 5.5 mm to give clearance to shield. Now 7 mil soldermask clearance between mounting hole and shield
    [swift-nav.brd, swift-nav.sch]
2012-04-05 Removed C47 and changed C48 from 0.01uF to 0.1uF
    [swift-nav.brd, swift-nav.sch]
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2012-05-18 Added XC2401 GPS LNA breakout board and put v2.2 in its own folder
    [lna_breakout.brd, lna_breakout.sch, swift-nav.brd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]
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2012-05-18 Putting v2.1 files in their own folder (just same files as v2_1 tag)
    [swift-nav.brd, swift-nav.sch]
2012-05-18 Changed board dims to 1.25x1.25 in for barebones specs Added more bare area around holes
    [xc2401_breakout.brd]
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2012-05-24 Added extra pages and partitioned design amongst pages to make it more neat. Snapped components and connections to grid where they weren't 100 mil snapped.
    [swift-nav.sch]
2012-05-24 In schematic: -Resistor between V_USB and STM USB detect pin -Add more FIFO lines from FPGA -Removed internal shield -Added LNA and associated components to LNA1 line -Changed LNA1 SMA to 1 thru hole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
    [swift-nav.brd, swift-nav.sch]
2012-05-25 Cleaned up RF section a little bit. Going to split MAX2769 symbol up a little bit more to clean it up further.
    [swift-nav.brd, swift-nav.sch]
2012-05-25 Cleaned up RF section a bit more - separated max2769 into 3 symbols
    [swift-nav.brd, swift-nav.sch]
2012-05-25 Added pull up resistors to NIDLE and NSHDN and pull down to PGM
    [swift-nav.brd, swift-nav.sch]
2012-05-25 Changed debug header to 12 pin with 1 gnd 1 VDD and 10 signal connections
    [swift-nav.brd, swift-nav.sch]
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2012-05-25 Debug connector was connected to VDD instead of V+ (post instead of pre-reverse polarity protection)
    [swift-nav.brd, swift-nav.sch]
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2012-05-26 Moved LNA2 SMA to line up with shield opening better
    [swift-nav.brd]
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2012-05-30 Routed rest of FTDI signals and added resistor to V_USB
    [swift-nav.brd]
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2012-06-06 Moving around some vias to reduce large gaps in ground plane
    [swift-nav.brd]
2012-06-07 Finished moving stuff around, routing, and DRC. Need to look at soldermask.
    [swift-nav.brd, swift-nav.sch]
2012-06-07 Couple part moves for spacing / solder mask clearance
    [swift-nav.brd]
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2012-06-11 Updated footprints and board with proper paste sizes
    [swift-nav.brd, swift-nav.sch]
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2012-07-03 Fixed stupid patch antenna ground pin via bug. Changed LNA footprint to 5 pin version. Fixed traces next to active antenna pin not meeting 6 mil clearance.
    [swift-nav.brd, swift-nav.sch]
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2012-07-03 Moved vias around to make silkscreen better, and re-DRC'd
    [swift-nav.brd]
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2012-07-25 Changed paste layer to make stencil gaps smaller and reduce probability of shorts during assembly
    [swift-nav.brd, swift-nav.sch]
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2012-08-15 Changed some RF matching inductor values and the red LED resistor value
    [swift-nav.brd, swift-nav.sch]
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2013-06-18 Changed frame, description, and added copyright/license notice for sheet 7
    [piksi.sch]
2013-06-18 Changed frame, description, and added copyright/license notice for sheet 6
    [piksi.sch]
2013-06-18 Changed frame, description, and added copyright/license notice for sheet 5
    [piksi.sch]
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2013-06-18 Changed frame, description, and added copyright/license notice for sheet 4
    [piksi.sch]
2013-06-18 Changed frame, description, and added copyright/license notice for sheet 3
    [piksi.sch]
2013-06-18 Changed frame, description, and added copyright/license notice for sheet 2
    [piksi.sch]
2013-06-18 Changed frame, description, and added copyright/license notice for sheet 1
    [piksi.sch]
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2013-06-18 Changed some text that looked weird in the pdf
    [piksi.sch]
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2013-06-27 Moved wire node up from USB pull down resistor for better cosmetics
    [piksi.brd, piksi.sch]
2013-11-21 Fixed errors eagle 6.5 was complaining about
    [piksi.brd, piksi.sch]
2013-11-21 Snapped all elements on schematic to 0.1 inch grid
    [piksi.brd, piksi.sch]
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

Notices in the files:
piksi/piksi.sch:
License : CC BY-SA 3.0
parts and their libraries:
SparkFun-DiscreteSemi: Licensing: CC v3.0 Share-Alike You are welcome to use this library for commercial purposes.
